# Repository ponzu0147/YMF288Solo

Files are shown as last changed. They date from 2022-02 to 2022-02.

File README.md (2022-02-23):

S98Player in ESP32 with YMF288.  
README.md is written by Japanese.  

ようこそ。

YMF288を使ったESP32(ESP-WROOM-32E)用 S98プレイヤーのプロジェクトです。  
機能の解説及び進捗状況はここに追記していきます。 

# 開発環境
Windows11 Pro  
WSL2 Ubuntu 18.04  
ESP-IDF

# 使用ハード
ESP32-DevKitC-32E(4MB) (https://akizukidenshi.com/catalog/g/gM-15673/)  
YMF288変換基板 GMC-MOD01 (https://gimic.jp/index.php?GMC-MOD01%E8%AA%AC%E6%98%8E)  
MicroSD用コネクタ変換基板 CK-40 (https://www.sunhayato.co.jp/material2/ucb08/item_490)  
ハイレゾリューションオーディオDACモジュール MM-5102 (https://www.sunhayato.co.jp/material2/ett09/item_765)

# 機能
### S98ファイルの再生
YM2608向けS98ファイルを再生します。  
現段階でADPCMには非対応（対応予定）  
その他の音源チップ向けデータの演奏は行いません。

### 物理ボタンによる選曲
1.次の曲に移動  
2.現在の曲を無限ループ再生（デフォルト：3ループ）  
3.前の曲に移動  

上記を3ボタンでの操作ができるようにしています。  
ディレクトリ内の最後・先頭のファイルの場合は、  
ディレクトリを跨いでの移動を可能としました。

### microSDカードからの読み取り
microSDカードのルートディレクトリおよび  
サブディレクトリ1段階までファイルを検索します。  
サブディレクトリの中にあるディレクトリには  
アクセスしません。

### リストファイルでのファイル管理
microSDカードのルートディレクトリに、  
s98.lst というファイルを作成します。  
このリストに記載されているS98ファイルの  
再生を行います。

現在は、電源投入後にSDカードへの検索を行い、  
リストファイルを作成してから演奏していますが、  
将来的にはユーザーによって任意のタイミングで  
リストの初期化、保存ができるようにします。  
（電源投入後すぐに演奏を始めるように待機時間の短縮をはかります）

### SSGボリューム簡易調整
YMF288はFM音源とSSG音源の音量バランスが、  
YM2608と異なっています。  
YM2608用のS98ファイルを再生すると、全体的に  
SSG音源の音量は小さめになってしまいます。

そこで現在はソースファイル内にて定義している、  
SSGボリュームを簡易的に調整する機能を付与しています。  
将来的にはFM音源部のキャリアの音量を減らす事で  
より自然なボリューム調整ができるようにします。

# 参考資料・謝辞(敬称略)
YM2608 OPNA アプリケーションマニュアル (c)YAMAHA  
YAMAHA LSI Data Book より YMF288 (c)YAMAHA  
GMC-MOD01 接続資料 (c)G.I.M.I.C Project([@gimicproject](https://twitter.com/gimicproject))  
s98dmp.c ソースファイル より s98フォーマット解析(Thanks for [@ume3fmp](https://twitter.com/ume3fmp/))  
ADPCM->PCM 変換ルーチン等 プログラム指南(Thanks for [@unn4m3cl](https://twitter.com/unn4m3cl/))  
[DAC出力フォーマット](https://github.com/osafune/fm_test_siggen/blob/master/doc/fmdac_output_format.pdf)(Thanks for [@s_osafune](https://twitter.com/s_osafune/))  

# 現在の課題(着手日)
2022/01/04 ソースのリファクタリング  
2022/01/09 ADPCM演奏  
2022/01/11 頭出し時のデータ化け対策  
~~2022/01/18 ver.0.1.1 試作基板作成(完了)~~  
~~2022/01/28 PCM5102AからFM/SSG演奏可能に(完了)~~  
2022/02/24 操作ボタンの仕様変更  
2022/xx/xx チャタリング対策・最適化  
2022/xx/xx リストの初期化・保存を任意に  
2022/xx/xx FM/SSG/RHYTHMの同期演奏ルーチン改良  

# リリース
2022/01/04 ver.0.1.0 初出  
2022/01/31 ver.0.1.1 基板作成にあたってGPIO番号の配置を変更  
2022/02/24 ver.0.1.2 ソフトウェア及び基板図とドキュメントの修正  

# ライセンス
ここにあるソース、ドキュメント、回路図、基板データについて  
Apache License 2.0 に基づきます。著作権は放棄しておりません。

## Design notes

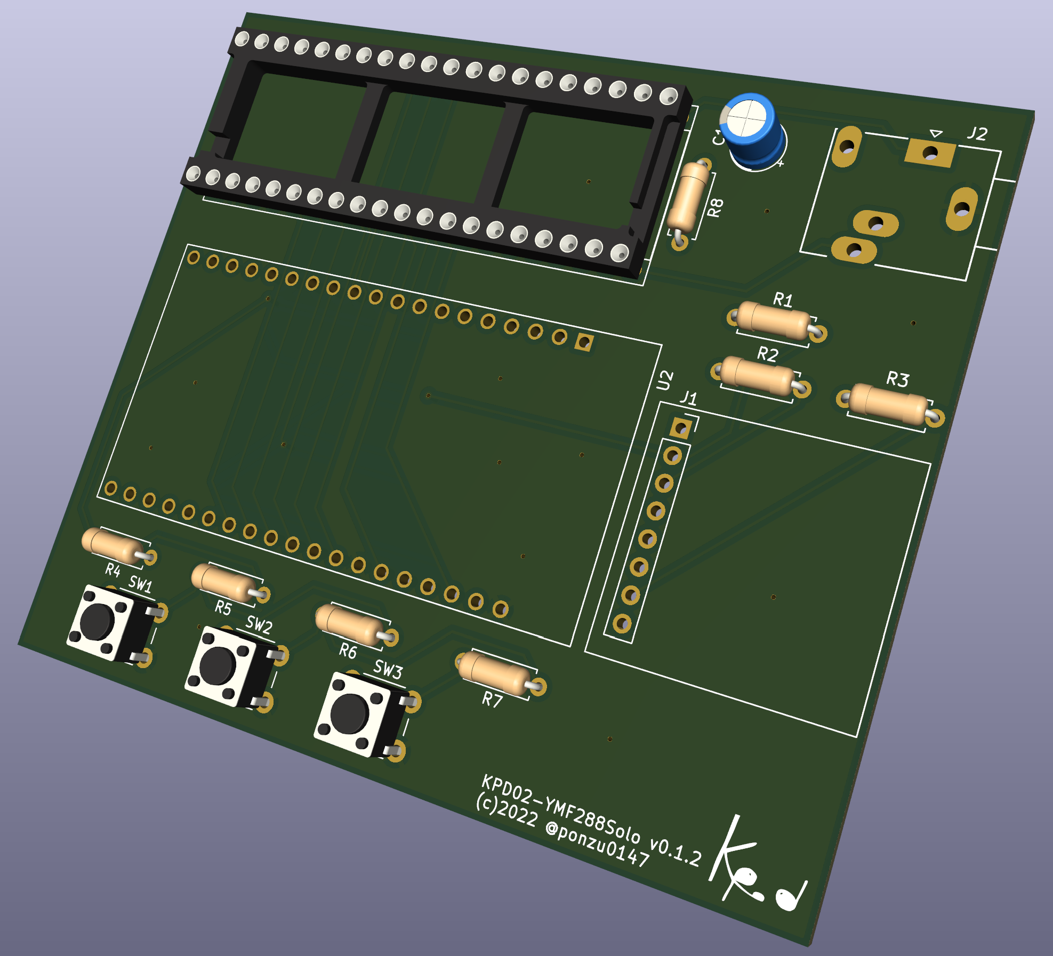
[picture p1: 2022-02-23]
doc/v.0.1.2/ymf288solo_layout_20220224_v.0.1.2.png

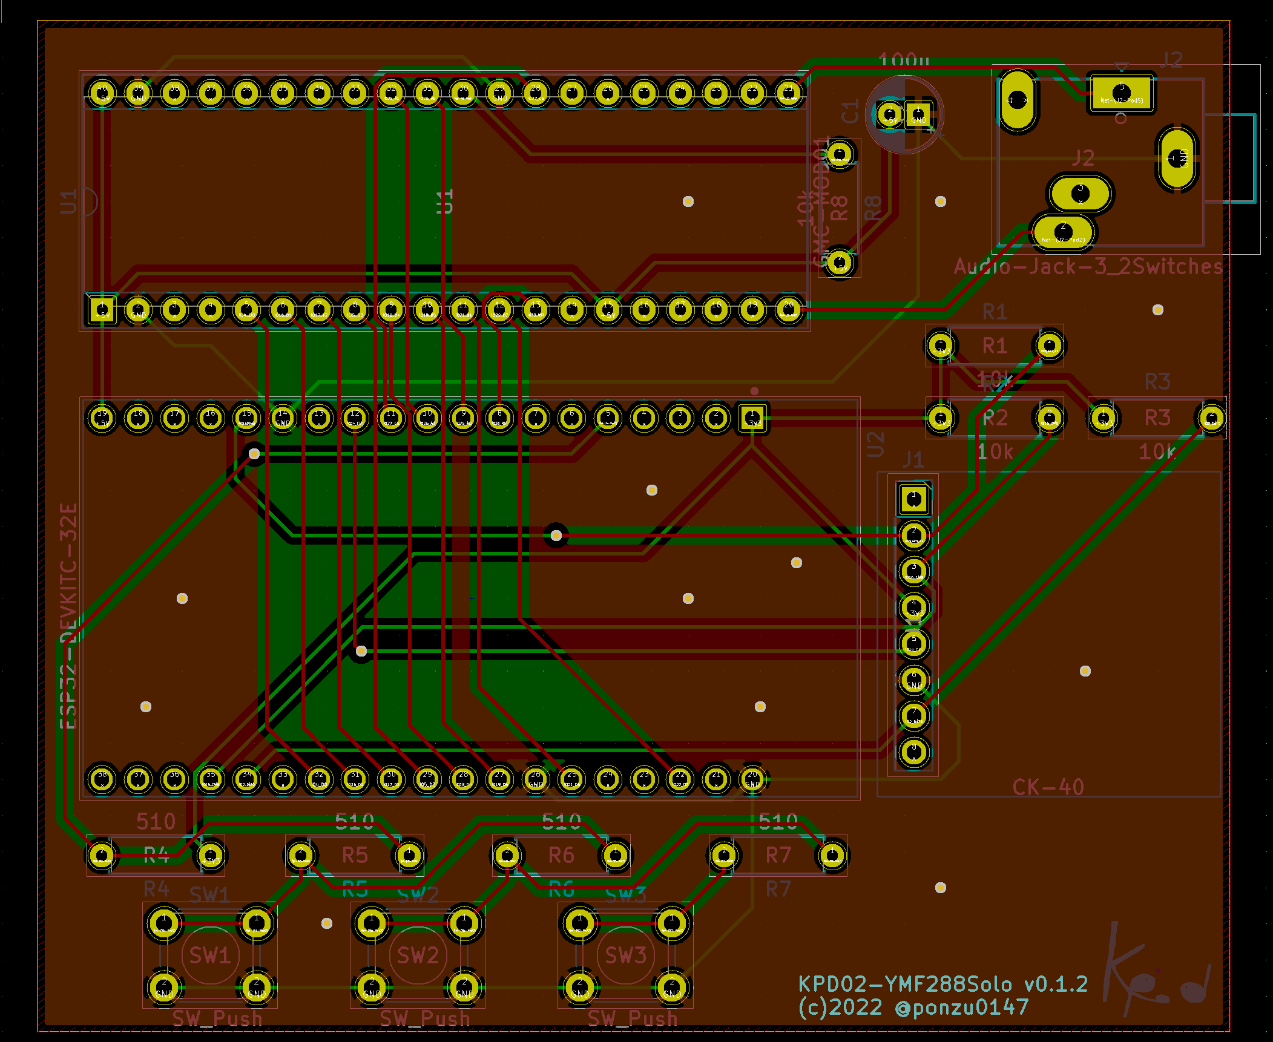
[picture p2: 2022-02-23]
doc/v.0.1.2/ymf288solo_pcb_20220224_v.0.1.2.png

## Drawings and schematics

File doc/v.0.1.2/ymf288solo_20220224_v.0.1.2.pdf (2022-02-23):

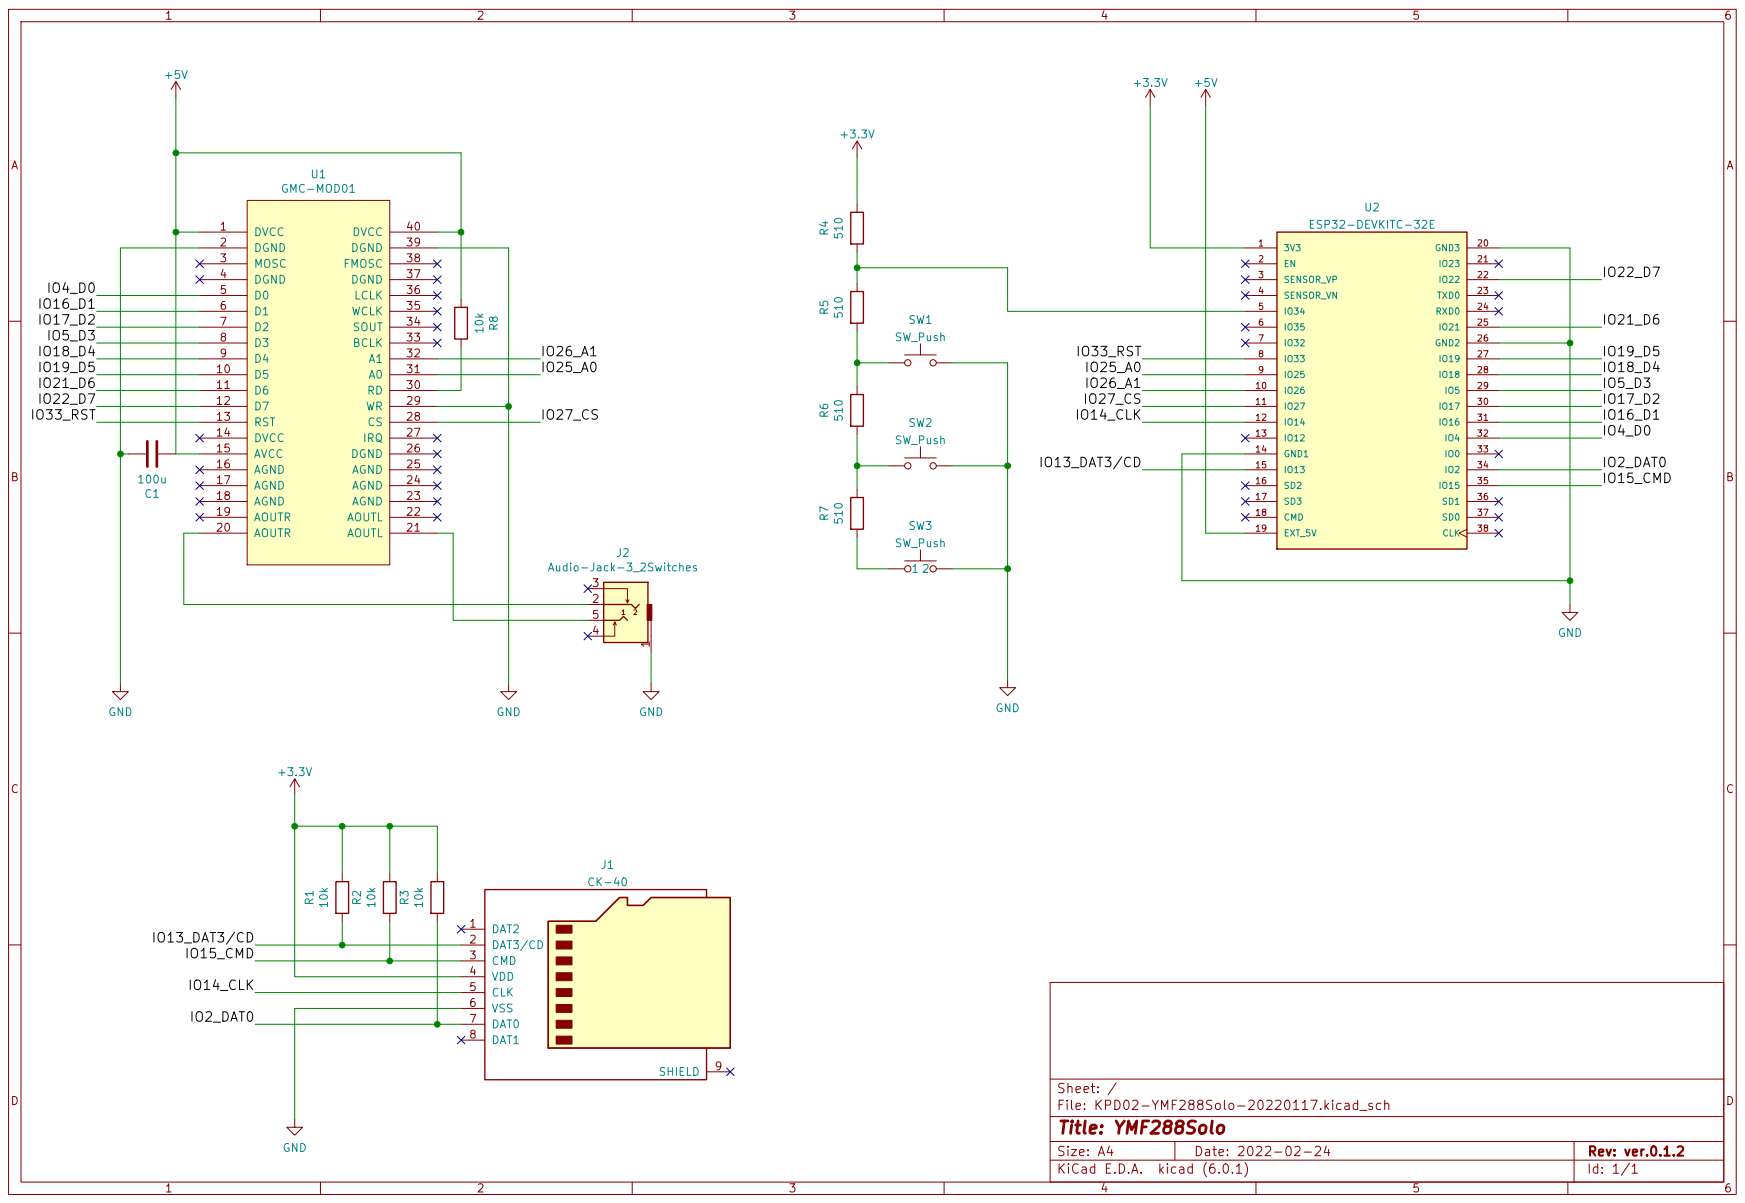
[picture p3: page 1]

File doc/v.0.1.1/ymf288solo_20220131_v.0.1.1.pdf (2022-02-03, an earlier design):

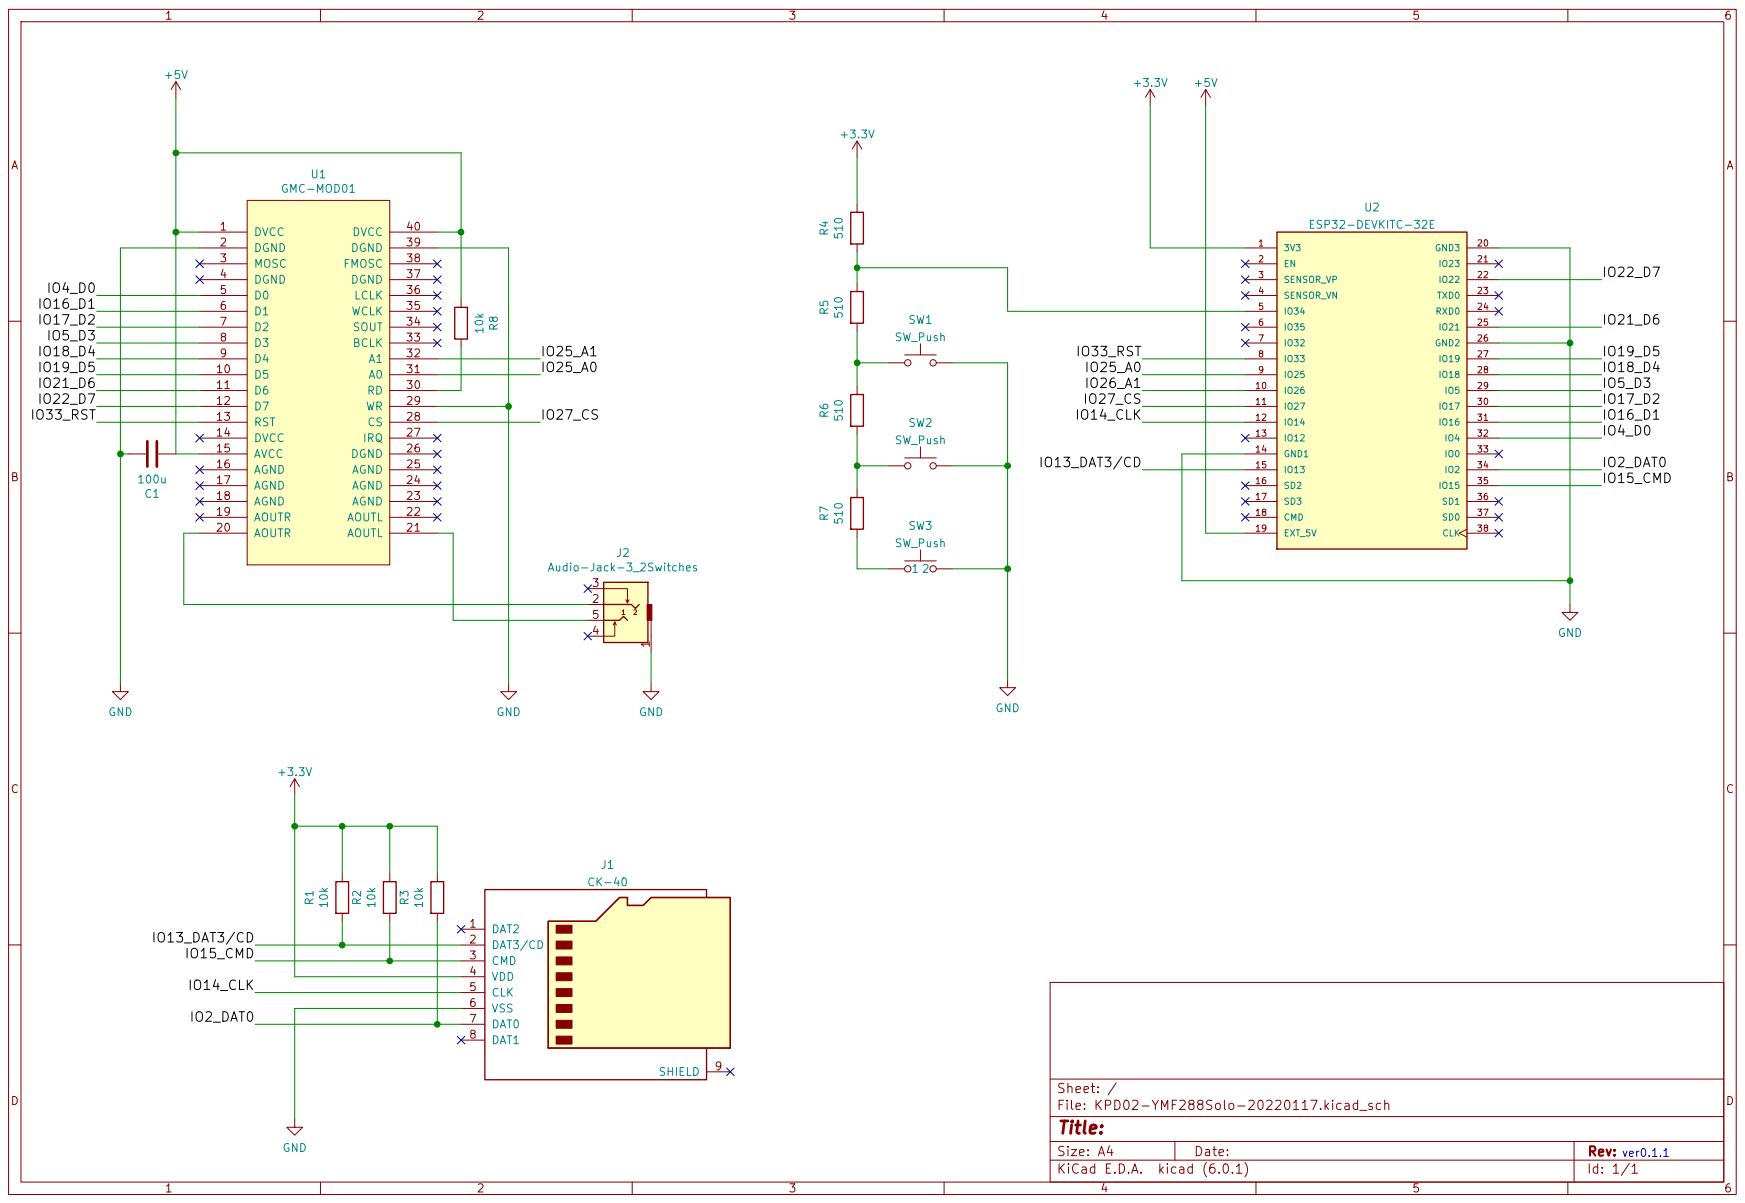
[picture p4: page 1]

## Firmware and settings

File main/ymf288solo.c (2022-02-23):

#include <string.h>
#include <sys/unistd.h>
#include <sys/stat.h>
#include "esp_vfs_fat.h"
#include "driver/sdmmc_host.h"
#include "sdmmc_cmd.h"
#include <dirent.h>
#include "s98.h"
#include <esp32/rom/ets_sys.h>
#include "freertos/FreeRTOS.h"
#include "freertos/task.h"
#include "freertos/queue.h"
#include "driver/timer.h"

#include <stdio.h>
#include "esp_timer.h"
#include "esp_log.h"
#include "esp_sleep.h"
#include "sdkconfig.h"

#include <stdlib.h>
#include "driver/gpio.h"
#include "driver/adc.h"
#include "esp_adc_cal.h"

#define DEFAULT_VREF    1100        //Use adc2_vref_to_gpio() to obtain a better estimate
#define NO_OF_SAMPLES   64          //Multisampling

static esp_adc_cal_characteristics_t *adc_chars;
static const adc_channel_t channel = ADC_CHANNEL_6;     //GPIO34 if ADC1, GPIO14 if ADC2
static const adc_atten_t atten = ADC_ATTEN_DB_11;
static const adc_unit_t unit = ADC_UNIT_1;

#define TIMER_DIVIDER         (16)  //  Hardware timer clock divider
#define TIMER_SCALE           (TIMER_BASE_CLK / TIMER_DIVIDER)  // convert counter value to seconds

typedef struct {
    int timer_group;
    int timer_idx;
    int alarm_interval;
    bool auto_reload;
} example_timer_info_t;

typedef struct {
    example_timer_info_t info;
    uint64_t timer_counter_value;
} example_timer_event_t;

static xQueueHandle s_timer_queue;

static bool IRAM_ATTR timer_group_isr_callback(void *args)
{
    BaseType_t high_task_awoken = pdFALSE;
    example_timer_info_t *info = (example_timer_info_t *) args;

    uint64_t timer_counter_value = timer_group_get_counter_value_in_isr(info->timer_group, info->timer_idx);

    /* Prepare basic event data that will be then sent back to task */
    example_timer_event_t evt = {
        .info.timer_group = info->timer_group,
        .info.timer_idx = info->timer_idx,
        .info.auto_reload = info->auto_reload,
        .info.alarm_interval = info->alarm_interval,
        .timer_counter_value = timer_counter_value
    };

    if (!info->auto_reload) {
        timer_counter_value += info->alarm_interval * TIMER_SCALE;
        timer_group_set_alarm_value_in_isr(info->timer_group, info->timer_idx, timer_counter_value);
    }

    /* Now just send the event data back to the main program task */
    xQueueSendFromISR(s_timer_queue, &evt, &high_task_awoken);

    return high_task_awoken == pdTRUE; // return whether we need to yield at the end of ISR
}

static void example_tg_timer_init(int group, int timer, bool auto_reload, int timer_interval_sec)
{
    /* Select and initialize basic parameters of the timer */
    timer_config_t config = {
        .divider = TIMER_DIVIDER,
        .counter_dir = TIMER_COUNT_UP,
        .counter_en = TIMER_PAUSE,
        .alarm_en = TIMER_ALARM_EN,
        .auto_reload = auto_reload,
    }; // default clock source is APB
    timer_init(group, timer, &config);

    /* Timer's counter will initially start from value below.
       Also, if auto_reload is set, this value will be automatically reload on alarm */
    timer_set_counter_value(group, timer, 0);

    /* Configure the alarm value and the interrupt on alarm. */
    timer_set_alarm_value(group, timer, timer_interval_sec * TIMER_SCALE / 100 ); // 10ms
    timer_enable_intr(group, timer);

    example_timer_info_t *timer_info = calloc(1, sizeof(example_timer_info_t));
    timer_info->timer_group = group;
    timer_info->timer_idx = timer;
    timer_info->auto_reload = auto_reload;
    timer_info->alarm_interval = timer_interval_sec/1000;
    timer_isr_callback_add(group, timer, timer_group_isr_callback, timer_info, 0);

    timer_start(group, timer);
}

static void check_efuse()
{
    //Check TP is burned into eFuse
    if (esp_adc_cal_check_efuse(ESP_ADC_CAL_VAL_EFUSE_TP) == ESP_OK) {
        printf("eFuse Two Point: Supported\n");
    } else {
        printf("eFuse Two Point: NOT supported\n");
    }

    //Check Vref is burned into eFuse
    if (esp_adc_cal_check_efuse(ESP_ADC_CAL_VAL_EFUSE_VREF) == ESP_OK) {
        printf("eFuse Vref: Supported\n");
    } else {
        printf("eFuse Vref: NOT supported\n");
    }
}

static void print_char_val_type(esp_adc_cal_value_t val_type)
{
    if (val_type == ESP_ADC_CAL_VAL_EFUSE_TP) {
        printf("Characterized using Two Point Value\n");
    } else if (val_type == ESP_ADC_CAL_VAL_EFUSE_VREF) {
        printf("Characterized using eFuse Vref\n");
    } else {
        printf("Characterized using Default Vref\n");
    }
}


// S98 header
unsigned char S98_ID[] = "S98";

// loop_count
int count_ff;

// buttons flag
volatile bool f_flag, p_flag, r_flag, q_flag, s_flag;
volatile bool switch_off = false;

// Max S98 version
#define MAXVER 3

char chipunknown[] = "[ UNKNOWN ]";
char *chip[] = {
	"NONE",				// 0
	"PSG(YM2149)",		// 1
	"OPN(YM2203)",		// 2
	"OPN2(YM2612)",		// 3
	"OPNA(YM2608)",		// 4
	"OPM(YM2151)",		// 5
	"OPLL(YM2413)",		// 6
	"OPL(YM3526)",		// 7
	"OPL2(YM3812)",		// 8
	"OPL3(YMF262)",		// 9
	"[ UNKNOWN ]",		// 10
	"[ UNKNOWN ]",		// 11
	"[ UNKNOWN ]",		// 12
	"[ UNKNOWN ]",		// 13
	"[ UNKNOWN ]",		// 14
	"PSG(AY-3-8910)",	// 15
	"DCSG(SN76489)"		// 16
};

static const char *TAG = "sdcard";

volatile int rep=1;

#define MOUNT_POINT "/sdcard"

// Pin mapping
#if CONFIG_IDF_TARGET_ESP32

#define PIN_NUM_MISO 2
#define PIN_NUM_MOSI 15
#define PIN_NUM_CLK  14
#define PIN_NUM_CS   13

#elif CONFIG_IDF_TARGET_ESP32S2

// adapted for internal test board ESP-32-S3-USB-OTG-Ev-BOARD_V1.0 (with ESP32-S2-MINI-1 module)
#define PIN_NUM_MISO 37
#define PIN_NUM_MOSI 35
#define PIN_NUM_CLK  36
#define PIN_NUM_CS   34

#elif CONFIG_IDF_TARGET_ESP32C3
#define PIN_NUM_MISO 6
#define PIN_NUM_MOSI 4
#define PIN_NUM_CLK  5
#define PIN_NUM_CS   1

#endif //CONFIG_IDF_TARGET_ESP32 || CONFIG_IDF_TARGET_ESP32S2

#if CONFIG_IDF_TARGET_ESP32S2
#define SPI_DMA_CHAN    host.slot
#elif CONFIG_IDF_TARGET_ESP32C3
#define SPI_DMA_CHAN    SPI_DMA_CH_AUTO
#else
#define SPI_DMA_CHAN    1
#endif

#define LOW 0
#define HIGH 1


unsigned char pin_set[7];
int S98_read(char* s98file);	

//fgets data strings
int fgsds(char **buf, const char *fname, int lines, int *len)
{
	FILE *fp = fopen(fname, "rb");
	if (fp == NULL) {
		printf("file open error!\n");
		return -1;
	}
	for (int i = 0; i < lines && fgets(buf[i], len[i] + 1, fp) != NULL; i++) {}
	fclose(fp);
	return 0;
}
 
//fgets list
int fgl(const char *fname)
{
	FILE *fp = fopen(fname, "rb");
	int c;
	int lines = 0; //count lines
	if (fp == NULL) {
		printf("file open error!\n");
		return -1;
	}
	
	while (1) {
		c = fgetc(fp);
		if (c == '\n') { 
			lines++;
		} else if (c == EOF) { //EOF is include
			lines++;
			break;
		}
	}
	
	fclose(fp);
	return lines;
}
 
//fgets length
int fglen(int *len, const char *fname)
{
	FILE *fp = fopen(fname, "rb");
	int c;
	int i = 0;
	int byt = 0; // count for byte
	int bytc = 0; // copy of byt
	if (fp == NULL) {
		printf("file open error!\n");
		return -1;
	}
	
	while (1) {
		c = fgetc(fp);
		byt++;
		if (c == '\n') {
			len[i] = byt - bytc;
			i++;
			bytc = byt;
		} else if (c == EOF) {
			if ((byt - bytc) <= 1) { // if return with /n
				len[i] = 0;
			} else {
				len[i] = byt - bytc; // if return without /n
			}
			break;
		}
	}
	
	fclose(fp);
	return 0;
}

void reset() {
    //YMF288 D0-D7
    gpio_set_direction(GPIO_NUM_4, GPIO_MODE_OUTPUT);
    gpio_set_direction(GPIO_NUM_16, GPIO_MODE_OUTPUT);
    gpio_set_direction(GPIO_NUM_17, GPIO_MODE_OUTPUT);
    gpio_set_direction(GPIO_NUM_5, GPIO_MODE_OUTPUT);
    gpio_set_direction(GPIO_NUM_18, GPIO_MODE_OUTPUT);
    gpio_set_direction(GPIO_NUM_19, GPIO_MODE_OUTPUT);
    gpio_set_direction(GPIO_NUM_21, GPIO_MODE_OUTPUT);
    gpio_set_direction(GPIO_NUM_22, GPIO_MODE_OUTPUT);

    gpio_set_direction(GPIO_NUM_25, GPIO_MODE_OUTPUT); // A0_
    gpio_set_direction(GPIO_NUM_26, GPIO_MODE_OUTPUT); // A1_
    gpio_set_direction(GPIO_NUM_27, GPIO_MODE_OUTPUT); // CS
    gpio_set_direction(GPIO_NUM_33, GPIO_MODE_OUTPUT); // RST

	gpio_set_direction(GPIO_NUM_34, GPIO_MODE_INPUT); // 3 buttons

    gpio_set_level(GPIO_NUM_33, HIGH); // CS


    gpio_set_level(GPIO_NUM_22, LOW); // RST 
    ets_delay_us(1000);
    gpio_set_level(GPIO_NUM_22, HIGH); // RST
    ets_delay_us(1000);

}

void write_data(unsigned char dat) {
    u_int32_t pin_set[8];
    /*
    char* pin_name[] = {
        "GPIO_PIN_4",
        "GPIO_PIN_16",
        "GPIO_PIN_17",
        "GPIO_PIN_5",
        "GPIO_PIN_18",
        "GPIO_PIN_19",
        "GPIO_PIN_21",
        "GPIO_PIN_22"
    };*/
     for ( int i=7; i >= 0; i-- ){
        pin_set[i] = (dat >> i ) & 1;
     }
        if (pin_set[0]) {
            GPIO.out_w1ts = (1 << 4);
        } else {
            GPIO.out_w1tc = (1 << 4);
        }
        if (pin_set[1]) {
            GPIO.out_w1ts = (1 << 16);
        } else {
            GPIO.out_w1tc = (1 << 16);
        }
        if (pin_set[2]) {
            GPIO.out_w1ts = (1 << 17);
        } else {
            GPIO.out_w1tc = (1 << 17);
        }
        if (pin_set[3]) {
            GPIO.out_w1ts = (1 << 5);
        } else {
            GPIO.out_w1tc = (1 << 5);
        }
        if (pin_set[4]) {
            GPIO.out_w1ts = (1 << 18);
        } else {
            GPIO.out_w1tc = (1 << 18);
        }
        if (pin_set[5]) {
            GPIO.out_w1ts = (1 << 19);
        } else {
            GPIO.out_w1tc = (1 << 19);
        }
        if (pin_set[6]) {
            GPIO.out_w1ts = (1 << 21);
        } else {
            GPIO.out_w1tc = (1 << 21);
        }
        if (pin_set[7]) {
            GPIO.out_w1ts = (1 << 22);
        } else {
            GPIO.out_w1tc = (1 << 22);
        }

/*
    gpio_set_level( GPIO_NUM_4, pin_set[0] );
    gpio_set_level( GPIO_NUM_16, pin_set[1] );
    gpio_set_level( GPIO_NUM_17, pin_set[2] );
    gpio_set_level( GPIO_NUM_5, pin_set[3] );
    gpio_set_level( GPIO_NUM_18, pin_set[4] );
    gpio_set_level( GPIO_NUM_19, pin_set[5] );
    gpio_set_level( GPIO_NUM_21, pin_set[6] );
    gpio_set_level( GPIO_NUM_22, pin_set[7] );
*/    
}

void law_write(unsigned char ifadr, unsigned char adr, unsigned char dat) {
    gpio_set_level(GPIO_NUM_25, LOW);       // A0=LOW
    if (ifadr) {
        gpio_set_level(GPIO_NUM_26, HIGH);  // A1=HIGH
    } else {
        gpio_set_level(GPIO_NUM_26, LOW);   // A1=LOW
    }
    write_data(adr);                  		// Address set
    gpio_set_level(GPIO_NUM_27, LOW);       // CS=LOW
    ets_delay_us(2);
    gpio_set_level(GPIO_NUM_27, HIGH);      // CS=HIGH
    ets_delay_us(1);

    gpio_set_level(GPIO_NUM_25, HIGH);      // A0=HIGH
    write_data(dat);                  		// Data set
    gpio_set_level(GPIO_NUM_27, LOW);       // CS
    ets_delay_us(2);
    gpio_set_level(GPIO_NUM_27, HIGH);      // CS
    //ets_delay_us(1);
}

void reg_write(unsigned char ifadr, unsigned char adr, unsigned char dat) {
    law_write(ifadr, adr, dat);
    switch (adr) { 							// Wait for data write
        case 0x28: { 						// FM Address 0x28
            ets_delay_us(29);  				// min: 24us wait
            break;
        }
        case 0x10: { 						// RHYTHM Address 0x10
            ets_delay_us(28);  				// min: 22us wait
            break;
        }
        default: { 							// Other Address
            ets_delay_us(4);  				// min.1.9us wait
        }
    }
}

// Convert byte to dword
int GetInt(unsigned char *_p) {
	int ret;
	ret = (_p[3]<<24) + (_p[2]<<16) + (_p[1]<<8) + _p[0];
	return ret;
}

void lntrim(char *str) {  
  char *p;  
  p = strchr(str, '\n');  
  if(p != NULL) {  
    *p = '\0';  
  }  
}  

char* cat_path(char* str1) {
    char* cp = NULL;
    cp = (char*)malloc(256);
    
    if (cp == NULL) {
        ESP_LOGE(TAG,"Can't create array!");
    }

    strcat(strcpy(cp,MOUNT_POINT),"/");
    strcat(cp,str1);
    ESP_LOGI(TAG,"Path: %s",cp);

    return cp;
}

char* cat_path_file(char* path, char* file) {
    //char* str1 = entry->d_name;
    char* cp = NULL;
    cp = (char*)malloc(256);
    
    if (cp == NULL) {
        ESP_LOGE(TAG,"Can't create array!");
    }

    strcat(strcpy(cp,path),"/");
    strcat(cp,file);
    ESP_LOGI(TAG,"Path  : %s",cp);

    return cp;
}

void S98_play2(char* s98file) {
    const char *ext = strrchr(s98file, '.');

    if (strcmp(ext,".S98") == 0 || strcmp(ext,".s98") == 0) {
            ESP_LOGI(TAG, "Extension is match. (%s)", ext);

            // FILE *fp;
			reset();
            ESP_LOGI(TAG, "Reading %s", s98file);

            if ( (S98_read(s98file)) == 1) {
                ESP_LOGE(TAG, "File open error! (%s)", s98file);
            } else {
                ESP_LOGI(TAG, "%s is close.", s98file);
            }
        } else {
            ESP_LOGI(TAG, "Extension is not match. (%s)", ext);
        }
    return;
}

void read_from_list(void* arg) {

    esp_err_t ret;

		esp_vfs_fat_sdmmc_mount_config_t mount_config = {
	#ifdef CONFIG_EXAMPLE_FORMAT_IF_MOUNT_FAILED
			.format_if_mount_failed = true,
	#else
			.format_if_mount_failed = false,
	#endif // EXAMPLE_FORMAT_IF_MOUNT_FAILED
			.max_files = 5,
			.allocation_unit_size = 16 * 1024
		};
		sdmmc_card_t *card;


		char mount_point[] = MOUNT_POINT;
		ESP_LOGI(TAG, "Initializing SD card");

		ESP_LOGI(TAG, "Using SPI peripheral");

		sdmmc_host_t host = SDSPI_HOST_DEFAULT();
		host.max_freq_khz = SDMMC_FREQ_HIGHSPEED;
		spi_bus_config_t bus_cfg = {
			.mosi_io_num = PIN_NUM_MOSI,
			.miso_io_num = PIN_NUM_MISO,
			.sclk_io_num = PIN_NUM_CLK,
			.quadwp_io_num = -1,
			.quadhd_io_num = -1,
			.max_transfer_sz = 16000,
		};
		ret = spi_bus_initialize(host.slot, &bus_cfg, SPI_DMA_CHAN);
		if (ret != ESP_OK) {
			ESP_LOGE(TAG, "Failed to initialize bus.");
			return;
		}

		sdspi_device_config_t slot_config = SDSPI_DEVICE_CONFIG_DEFAULT();
		slot_config.gpio_cs = PIN_NUM_CS;
		slot_config.host_id = host.slot;

		ESP_LOGI(TAG, "Mounting filesystem");
		ret = esp_vfs_fat_sdspi_mount(mount_point, &host, &slot_config, &mount_config, &card);

		if (ret != ESP_OK) {
			if (ret == ESP_FAIL) {
				ESP_LOGE(TAG, "Failed to mount filesystem. "
						"If you want the card to be formatted, set the EXAMPLE_FORMAT_IF_MOUNT_FAILED menuconfig option.");
			} else {
				ESP_LOGE(TAG, "Failed to initialize the card (%s). "
						"Make sure SD card lines have pull-up resistors in place.", esp_err_to_name(ret));
			}
			return;
		}
		ESP_LOGI(TAG, "Filesystem mounted");

		sdmmc_card_print_info(stdout, card);

    FILE *lp;
    DIR *dir;
    int k=0;

    const char *list_file2 = MOUNT_POINT"/s98.lst";

    if ((dir = opendir(MOUNT_POINT)) == NULL) {
      ESP_LOGE(TAG, "Directory is not found.");
    } else {

    lp = fopen(list_file2,"r");
    if (lp == NULL) {
        fprintf(stderr, "List open error.\n");
        return;
    }

	// fgsds
	int lines = fgl(list_file2); //fgl関数を用いて、ファイルの行数を取得
	int *len = (int *)malloc(lines * sizeof(int)); //int型の配列lenの配列数（行数）を設定
	fglen(len, list_file2); //fglen関数を用いて、配列lenに行ごとのバイト数を入れる
	char **buf = (char **)malloc(lines * sizeof(char *)); //格納配列[buf]に行数を確保
	for (int i = 0; i < lines; i++) {
		buf[i] = (char *)malloc((len[i] + 1) * sizeof(char)); //各行に文字列を格納するメモリを確保
	}
	fgsds(buf, list_file2, lines, len); //fgsds関数を用いて、二次元配列bufにファイルの文字列データを格納

    // Read a list from file
    while(1){

		if(q_flag == true){
			k=k-1;
			if(k<=0){
				k=lines-2;
			} else {
				k = k- 1;
			}
			q_flag = false;
		}

		//改行コードを削除する
		int last = strlen(buf[k]) - 1;
		if (last >= 0 && buf[k][last] == '\n') {
			buf[k][last] = '\0';
		} 
        if(k==lines-1){
            fseek(lp,0,SEEK_SET); // 先頭に戻る
            k=0;
        } else {
			printf("Current number: %d\n",k);
			printf("Playing file: %s\n",buf[k]);
            S98_play2(buf[k]);
			k++;
        }
    }

	//メモリの解放
	for (int i = 0; i < lines; i++) {
		free(buf[i]); //各行のメモリを解放
	}
	free(buf);
	free(len);

    fclose(lp);
    closedir(dir);
    }
}
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
void app_main(void)
{
    reset();

    //Check if Two Point or Vref are burned into eFuse
    check_efuse();

    //Configure ADC
    if (unit == ADC_UNIT_1) {
        adc1_config_width(ADC_WIDTH_BIT_12);
        adc1_config_channel_atten(channel, atten);
    } else {
        adc2_config_channel_atten((adc2_channel_t)channel, atten);
    }

    //Characterize ADC
    adc_chars = calloc(1, sizeof(esp_adc_cal_characteristics_t));
    esp_adc_cal_value_t val_type = esp_adc_cal_characterize(unit, atten, ADC_WIDTH_BIT_12, DEFAULT_VREF, adc_chars);
    print_char_val_type(val_type);

    s_timer_queue = xQueueCreate(10, sizeof(example_timer_event_t));

    example_tg_timer_init(TIMER_GROUP_0, TIMER_0, true, 1);

    //Write S98 list file
    s98file_check();

    xTaskCreate(&key_check, "Task1", 2048, NULL, 5, NULL);
    xTaskCreate(&read_from_list, "Task2", 8192, NULL, 5, NULL);

}

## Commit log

2022-01-31 GPIO pin assign changed.
2022-02-03 add v.0.1.1 pcb data.
    [KPD02-YMF288Solo-20220117-B_Cu.gbl, KPD02-YMF288Solo-20220117-B_Mask.gbs, KPD02-YMF288Solo-20220117-B_Paste.gbp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]
2022-02-20 GPIO pin assign modified.
2022-02-23 release v.0.1.2 pcb and document.
    [KPD02-YMF288Solo-20220117-B_Cu.gbl, KPD02-YMF288Solo-20220117-B_Mask.gbs, KPD02-YMF288Solo-20220117-B_Paste.gbp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]
